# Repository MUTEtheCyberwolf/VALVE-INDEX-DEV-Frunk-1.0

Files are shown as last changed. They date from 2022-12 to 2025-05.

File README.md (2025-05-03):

index_hmd_assembly v29cropped
# VALVE-INDEX-DEV-Frunk-1.0

Mounting System for Developers and Endusers to modify their **Valve Index HMD**.

This Solution is designed to be more **"Beginner"** friendly as well as more open for Modifications. You have a idea for an VR Accessory? Feel free to use the
M4 Mounting points to fix it to your Headset.

## THIS Modification will NOT Void your Headsets Warranty if done properly

# !!! UNPLUG YOUR HEADSET BEFORE WORKING ON IT !!!

# DF1.0 will be marked as complete with the Upload of the Babble Facial Bridge adapter. I am working on a new System the [DF2.0](https://github.com/MUTEtheCyberwolf/Valve-Index-Dev-Frunk-2.0) which will most likely replace the DF1.0 in the long term. Thanks to everyone who supported this first Era of a Open Source Hardware Modding Platform of the INDEX <3

## Repository includes:
 - Base Mounting Frunk
 - HTC VIVE Facial Tracker Mount
 - Project Babble Facetracker Mount (Infograph needs to be updated. You dont need the VIDEV parts but only the FacialTrackerBridgeBABBLEFrunk1.stl/3mf)
 - EyetrackVR Mount (XIAO Boards)
 - EyetrackVR Mount (ESPCAM Boards)
 - VROptician IR Ringlight Mounts (Only works with V2 Lenses) SOON to be Released
 - VROptician EyetrackVR V4 LED Mounts

### These Instructions will show you how to assemble the Mount Parts. You will need additional Parts for the EyetrackVR Tracking. Please take a look at [EyetrackVR Docs](https://docs.eyetrackvr.dev/how_to_build/parts_list) Page.

## Things you need for this Modification:
 - 3D Printer or a 3D Print Service ([PCBWay](https://www.pcbway.com/rapid-prototyping/manufacture/?type=2&reffercode=TOP) or [JLCPCB](https://www.jlc3dp.com/3d-printing-quote) for example)
 - Soldering Iron (I can highly recommend either a [TS101](https://www.welectron.com/Miniware-Soldering-Iron-TS101-I) or a [PINECIL](https://pine64.com/product/pinecil-smart-mini-portable-soldering-iron/). Any cheap 110/230V one also does the Trick)
 - Threaded Heat Inserts. I recommend them either from [Ruthex](https://www.ruthex.de/collections/gewindeeinsatze/products/ruthex-gewindeeinsatz-m4-50-stuck-rx-m4x8-1-messing-gewindebuchsen) or [CNC Kitchen](https://cnckitchen.store/de/products/gewindeeinsatz-threaded-insert-m4-standard-50-stk-pcs)
 - A T5 Torx Screwdriver [iFixit T5 Screwdriver](https://store.ifixit.de/products/t5-torx-screwdriver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) or [iFixit Pro Tech Toolkit](https://store.ifixit.de/products/pro-tech-toolkit) (HIGHLY Recommended)
 - USB-A to USB-C Adaptercable [Choose S1-T5A 10cm](https://de.aliexpress.com/item/1005001319263765.html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) (For now until i release my Fan driver and USB Passthrough Board)
 - RF Shielding Tape [TITAN RF](https://www.amazon.de/TitanRF-Faraday-Tape-High-Shielding-Conductive/dp/B07CRLCGCH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,aps,109) (For the USB Cable)
 - M4 Screws [Amazon Link](https://www.amazon.de/Innensechskantschraube-Edelstahl-Sechskantschraube-Mechanische-Kombinationsbox/dp/B07PRWDHQL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,aps,105) (You will need 6x M4x10/15 and 1x M4x30 for Full Coverage)



index_hmd_assembly v28

# ETVR In Action with DEV Frunk 1.0 and GEN 3 IR Ringlight (Work in Progress)

I am currently tracking only the Right Eye to find the perfect Placement. 

Link to the OSHW Directory of my V1 ETVR Tracking PCB. (ONLY RECOMMENDED FOR PEOPLE WHO KNOW WHAT THEY ARE DOING)
[OSHWLAB Link](https://oshwlab.com/mutethecyberwolf/universal-tracking-module-v1-stt-hub-xiao)

Link to EyeTrackVR: https://github.com/EyeTrackVR

https://github.com/MUTEtheCyberwolf/VALVE-INDEX-DEV-Frunk-1.0/assets/98415183/26b2f5b6-8aac-414c-be2f-e947e9494397

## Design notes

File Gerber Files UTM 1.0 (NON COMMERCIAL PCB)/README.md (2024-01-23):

# THIS VERSION IS ONLY A PROOF OF CONCEPT !

The used IR LED Driver has some Designflaws and can result in high Eyestrain or in worst cases to permanent Eye Damage.
Only try this Build if you know what your doing (or at least more than i do lol) 

## I WILL NOT BE MADE ACCOUNTABLE FOR DAMAGES THAT RESULT FROM INPROPER USE OF THESE RESOURCES!!!

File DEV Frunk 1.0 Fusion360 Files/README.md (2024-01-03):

# VALVE-INDEX-DEV-Frunk-1.0

Here are the Fusion360 Files for User Customization. Feel free to alter them to your Desires but please when Posting Pictures of them refer them to this GitHub Repository.
I will try to keep everything kinda Updated and also continue on improving the HW Designs in the Future. Due to work and other Duties this can sometimes take a while tho so please be patient.

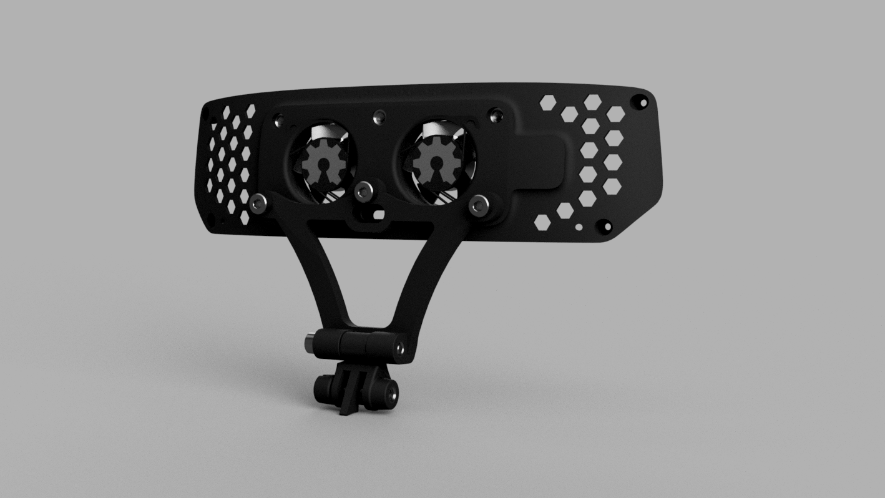
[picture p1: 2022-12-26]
Pictures/VIDEVFrunk1.png

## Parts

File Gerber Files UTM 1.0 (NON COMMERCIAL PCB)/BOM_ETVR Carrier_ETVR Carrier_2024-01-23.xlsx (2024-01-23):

No. | Quantity | Comment | Designator | Footprint | Value | Manufacturer Part | Manufacturer | Supplier Part | Supplier
1 | 4 | 100nF | C1,C2,C4,C6 | C0603 |  | 0603B104M250NT | FH(风华) | C336628 | LCSC
2 | 2 | 10uF | C3,C5 | C0603 |  | 0603F106M6R3NT | FH(风华) | C138601 | LCSC
3 | 4 | 4.7uF | C7,C8,C9,C13 | CAP-SMD_L3.5-W2.8-R-RD |  | TAJB475K035RNJ | Kyocera AVX | C7206 | LCSC
4 | 2 | 100uF | C11,C12 | CASE-B_3528 |  | TAJB107K006RNJ | Kyocera AVX | C16133 | LCSC
5 | 2 | ZHCS400QTA | D1,D2 | SOD-323_L1.8-W1.3-LS2.5-RD |  | ZHCS400QTA | DIODES(美台) | C460116 | LCSC
6 | 2 | BZX384-B3V6,115 | D3,D4 | SOD-323_L1.7-W1.3-LS2.5-RD |  | BZX384-B3V6,115 | Nexperia(安世) | C78071 | LCSC
7 | 2 | NO | DAC/D0/A1,DAC/D0/A2 | SEEEDUINO XIAO ESP32S3 |  | Xiao | Seeeduino |  | Amazon
8 | 1 | FSMD100-1206R | F2 | F1206 |  | FSMD100-1206R | FUZETEC(富致) | C220149 | LCSC
9 | 3 | USB-TYPE-C-017 | FACETRACKER,HOST,SPARE | USB-TYPE-C-SMD_C9900008089 |  | USB-TYPE-C-017 | DEALON(德艺隆) | C2927037 | LCSC
10 | 2 | HC-1.25-4PWT | IRLINKLEFT,IRLINKRIGHT | CONN-SMD_4P-P1.25-HC-1.25-4PWT |  | HC-1.25-4PWT | HCTL(华灿天禄) | C2845381 | LCSC
11 | 2 | 4.7uH | L1,L2 | IND-SMD_L2.0-W1.6 |  | CKCS201610-4.7uH/M | CENKER(岑科) | C354534 | LCSC
12 | 2 | NCD3227YC1 | LED1,LED2 | LED-SMD_4P-L3.2-W2.7-TL |  | NCD3227YC1 | 国星光电 | C2917183 | LCSC
13 | 1 | 2.7kΩ | R1 | R0603 |  | AC0603DR-072K7L | YAGEO(国巨) | C227482 | LCSC
14 | 3 | 100kΩ | R2,R3,R4 | R0603 |  | RTT031003FTP | RALEC(旺诠) | C103200 | LCSC
15 | 1 | 47kΩ | R5 | R0603 |  | FRC0603J473 TS | FOJAN(富捷) | C2907173 | LCSC
16 | 4 | 56kΩ | R6,R9,R10,R11 | R0402 |  | AECR0402F56K0K9 | RESI(开步睿思） | C352409 | LCSC
17 | 2 | 5.1kΩ | R7,R8 | R0402 |  | 0402WGJ0512TCE | UNI-ROYAL(厚声) | C25941 | LCSC
18 | 4 | 100Ω | R12,R13,R16,R17 | R0603 |  | AC0603DR-07100RL | YAGEO(国巨) | C227435 | LCSC
19 | 2 | 330Ω | R14,R15 | R0603 |  | PTFR0603B330RP9 | RESI(开步睿思） | C351654 | LCSC
20 | 2 | 1kΩ | R18,R19 | R0603 |  | SCR0603J1K | VO(翔胜) | C3017736 | LCSC
21 | 2 | - | U1,U7 | QFN-8_L3.0-W3.0-P0.65-TL-EP |  | TPS61042DRBR | TI(德州仪器) | C91304 | LCSC
22 | 2 | S3B-PH-K-S-(LF)(SN) | U2,U6 | CONN-TH_3P-P2.00_S3B-PH-K-S-LF-SN |  | S3B-PH-K-S(LF)(SN) | JST | C157929 | LCSC
23 | 1 | FE1.1S | U4 | SSOP-28_L9.9-W3.9-P0.64-LS6.0-BL-1 |  | FE1.1S-BSOP28BCN | TERMINUS | C9359 | LCSC
24 | 1 | - | X1 | OSC-SMD_4P-L3.2-W2.5-BL |  | XXFCELNANF-12M | TAITIEN(泰艺电子) | C124308 | LCSC

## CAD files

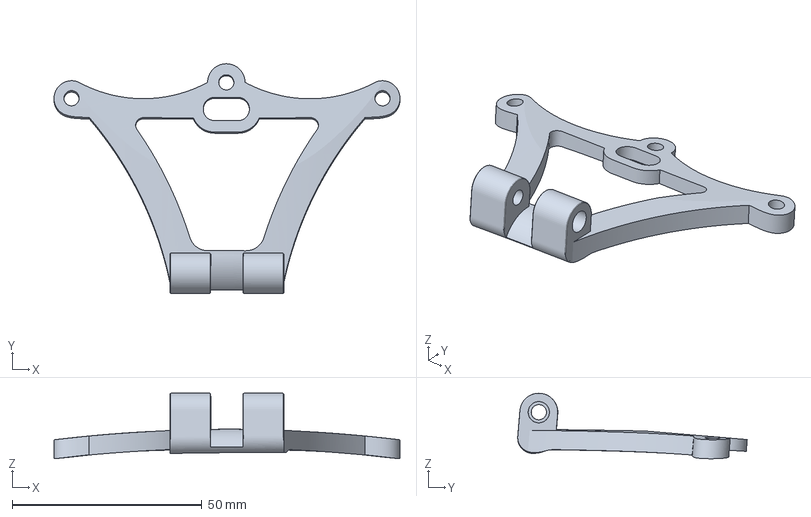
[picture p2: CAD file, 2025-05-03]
3D Print Files 3mf/FacialTrackerBridgeBABBLEFrunk1.3mf
91.1 x 60.5 x 17.3 mm

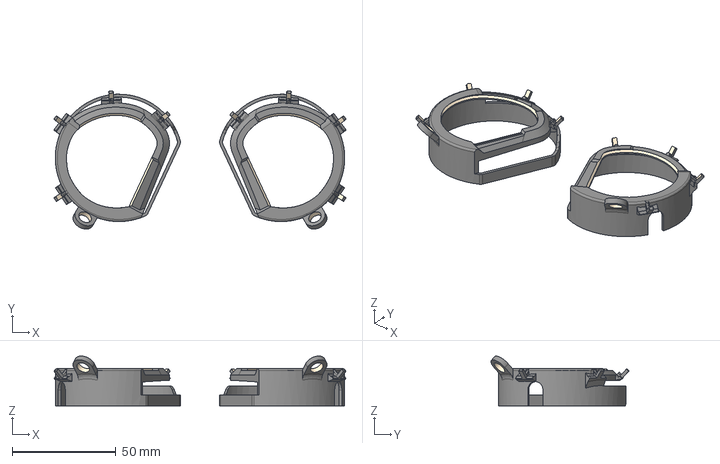
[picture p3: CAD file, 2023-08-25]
3D Print Files STL(Ascii)/Gen 3 Prohurtz V2 Mounts (VROptician)/MUTE VROptician Gen 3 Mounts for Prohurtz V2 IR LED's.step
140.9 x 66.7 x 24.1 mm

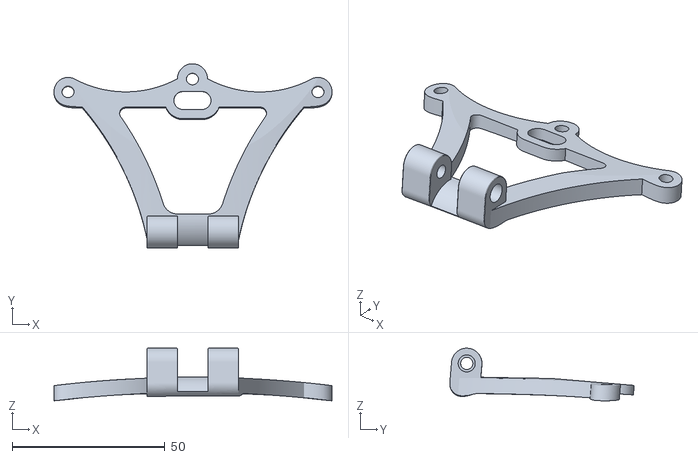
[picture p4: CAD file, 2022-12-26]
Basic Setup for Vive Facial Tracker/FacialTrackerBridgeVIDEVFrunk1.stl
91.1 x 60.5 x 17.3

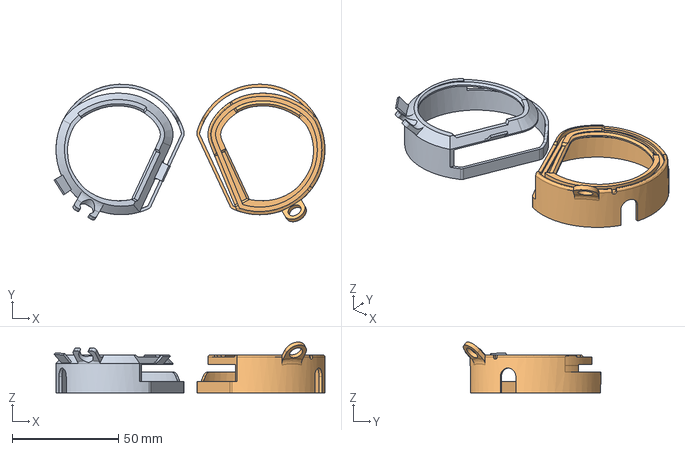
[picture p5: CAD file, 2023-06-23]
INDEX VROptician Gen 3 Lense Mounts (Prototype not final)/Index Lense Carrier Gen 3.step
127.6 x 64.8 x 24.0 mm

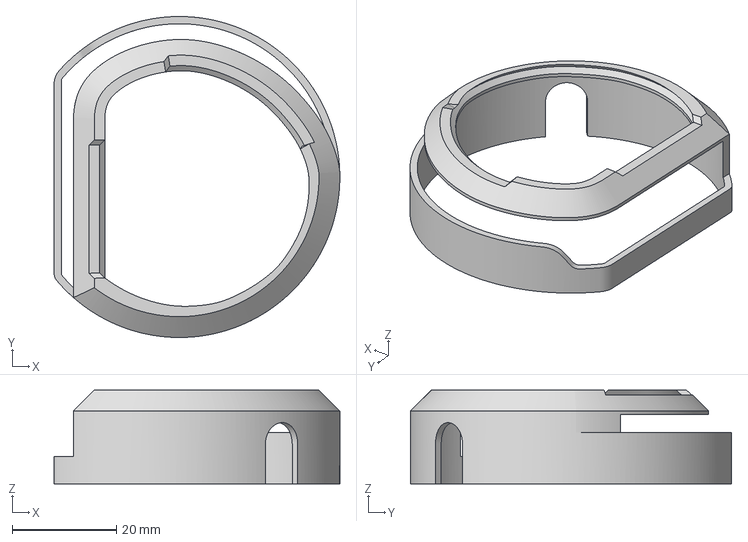
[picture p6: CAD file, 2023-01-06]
INDEX VROptician LENSE Base + Edits/ETVR INDEX VROptician LENSE Mount.3mf
54.7 x 61.5 x 18.0 mm

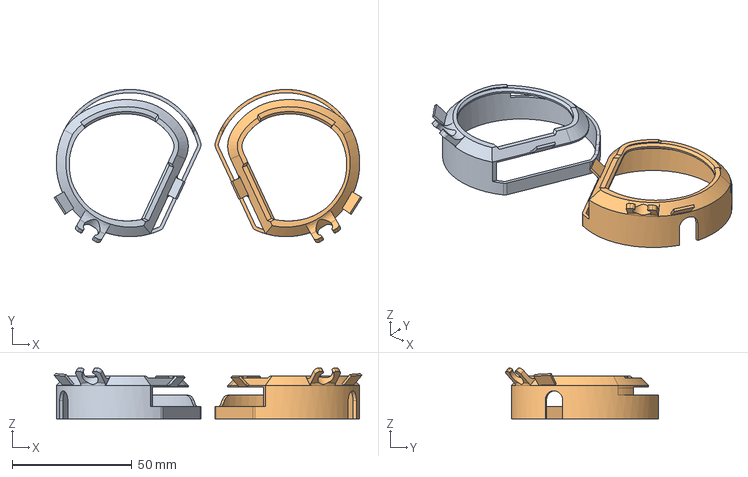
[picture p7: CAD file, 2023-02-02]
INDEX VROptician LENSE Base + Edits/V1.0A Edit with Twin LED and Camera Mount/INDEX VROptician Lense Mounts (2022).step
128.6 x 63.9 x 21.2 mm

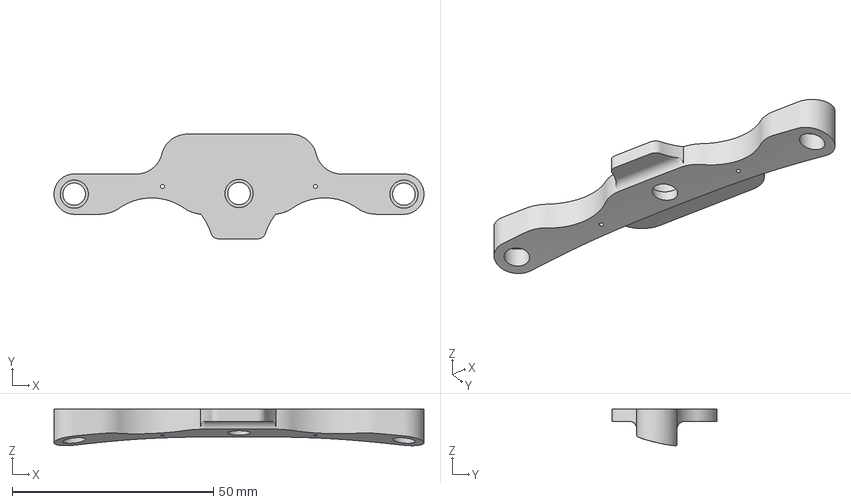
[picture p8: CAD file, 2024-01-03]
3D Print Files 3mf/UTM V1.0 Mount.3mf
91.9 x 26.0 x 9.08 mm

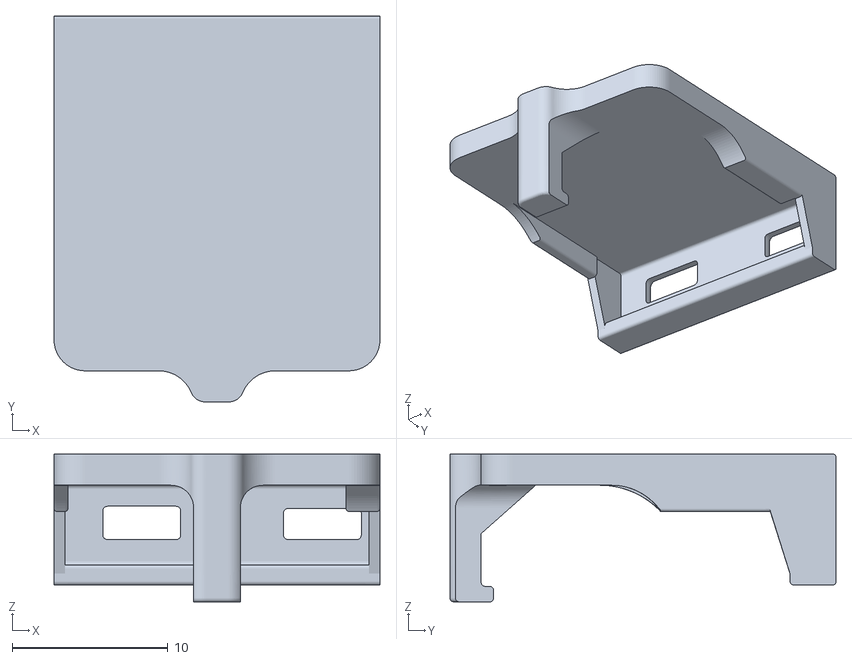
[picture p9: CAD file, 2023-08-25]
3D Print Files STL(Ascii)/Coverplate XIAO Retention Clip V4 PCB No Logo.stl
20.9 x 24.8 x 9.49

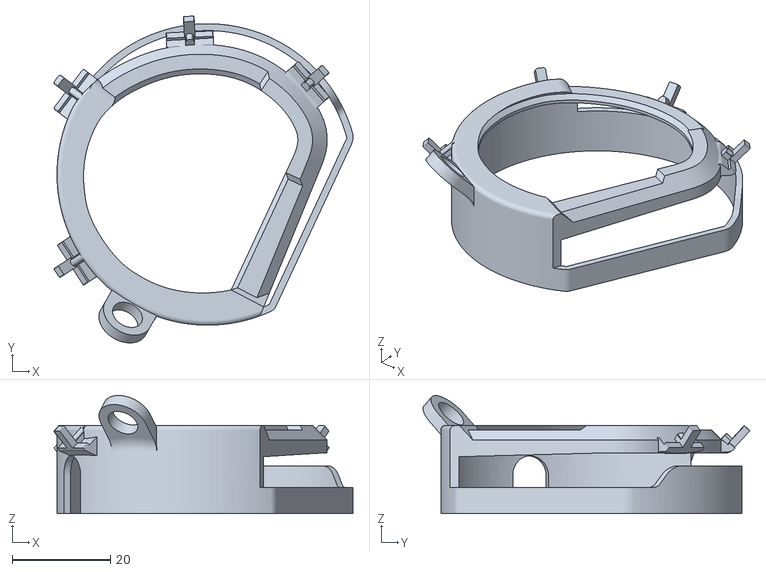
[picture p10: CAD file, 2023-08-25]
3D Print Files STL(Ascii)/Gen 3 Prohurtz V2 Mounts (VROptician)/Gen_3_Prohurtz_V2_Mount Verified (Tight Fit) L.stl
61.0 x 66.7 x 24.1

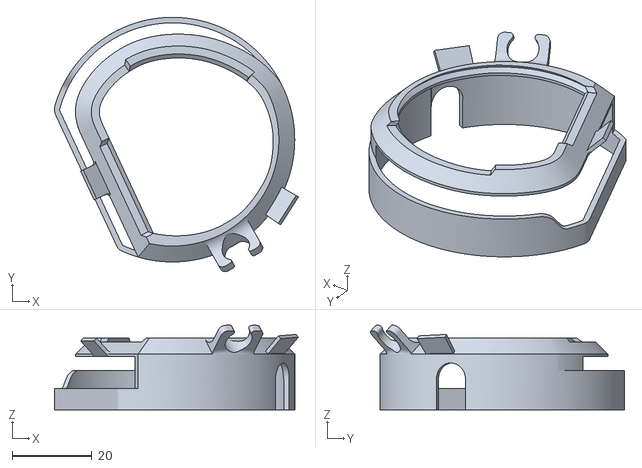
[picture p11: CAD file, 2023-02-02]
INDEX VROptician LENSE Base + Edits/V1.0A Edit with Twin LED and Camera Mount/INDEX VROptician Lense Mounts (2022) Right.stl
61.3 x 63.9 x 21.2

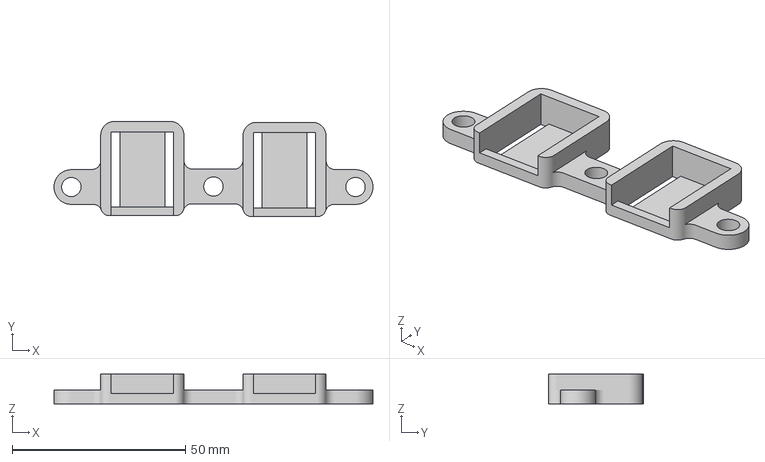
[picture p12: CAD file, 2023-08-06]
3D Print Files 3mf/Eyetrack VR Prototype XIAO.3mf
92.0 x 27.5 x 8.60 mm

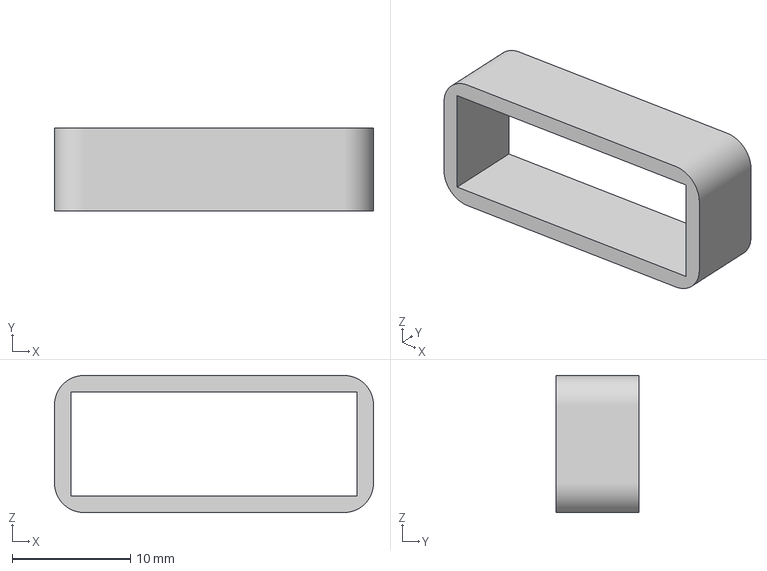
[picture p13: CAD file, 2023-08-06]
3D Print Files 3mf/XIAO Retention Clip.3mf
27.0 x 7.00 x 11.6 mm

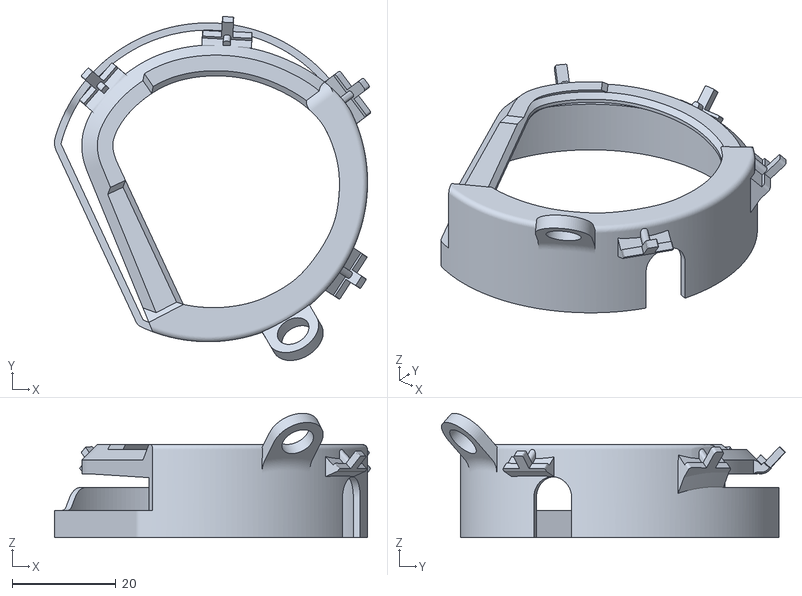
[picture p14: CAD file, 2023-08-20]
3D Print Files STL(Ascii)/Gen_3_Prohurtz_V2_Mount Unverified.stl
61.0 x 66.4 x 24.0

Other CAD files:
3D Print Files STL(Ascii)/FacialTrackerBridgeBABBLEFrunk1.stl
INDEX VROptician LENSE Base + Edits/ETVR INDEX VROptician LENSE Mounts.step
3D Print Files STL(Ascii)/Coverplate for XIAO Retention Clip V4 PCB.stl
3D Print Files STL(Ascii)/Gen 3 Prohurtz V2 Mounts (VROptician)/Gen_3_Prohurtz_V2_Mount Verified (Tight Fit) R.stl
INDEX VROptician LENSE Base + Edits/V1.0A Edit with Twin LED and Camera Mount/INDEX VROptician Lense Mounts (2022) Left.stl
3D Print Files 3mf/EyetrackVRDemoVIDEVFrunk1.3mf
3D Print Files 3mf/FacialTrackerBeerHingeVIDEVFrunk1.3mf
3D Print Files 3mf/FacialTrackerBridgeVIDEVFrunk1.3mf
3D Print Files 3mf/ValveIndexDEVFrunk1.3mf
3D Print Files STL(Ascii)/Eyetrack VR Prototype XIAO Mount.stl
3D Print Files STL(Ascii)/EyetrackVRDemoVIDEVFrunk1.stl
3D Print Files STL(Ascii)/XIAO Retention Clip for V4 PCB No Letters.stl
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

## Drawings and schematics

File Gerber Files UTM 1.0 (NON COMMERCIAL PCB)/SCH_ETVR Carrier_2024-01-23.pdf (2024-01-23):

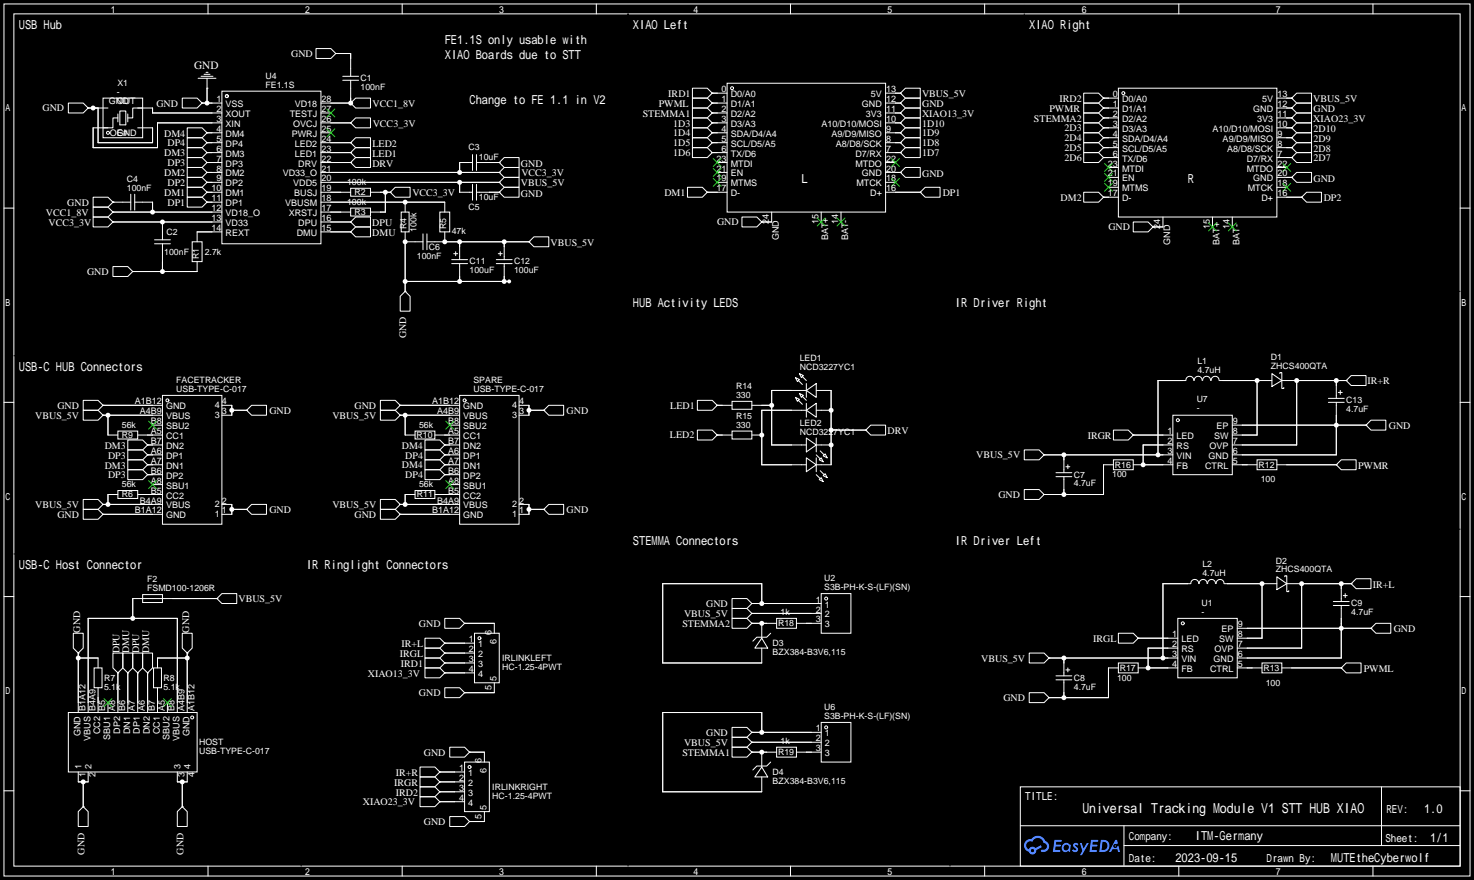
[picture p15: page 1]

FE1.1S only usable with
XIAO Boards due to STT

Change to FE 1.1 in V2

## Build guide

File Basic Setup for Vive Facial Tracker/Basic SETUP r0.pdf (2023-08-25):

MUTE | VALVE INDEX DEV FRUNK 1.0 HW INSTALLATION GUIDE | Rev. 0

Thank you for downloading the VALVE INDEX DEV FRUNK 1.0 3D Printing Files.

This Document should help you with:

- Getting the necessary Parts printed
- Insert the threaded Inserts into your Part
- Removing the Factory Frunk from your INDEX HMD
- Installing the DEV Frunk in your HMD
- Connecting the Facial Tracker to your HMD

Before we Start one little Reminder.

So what Parts do we need except the 3D Printed Parts?

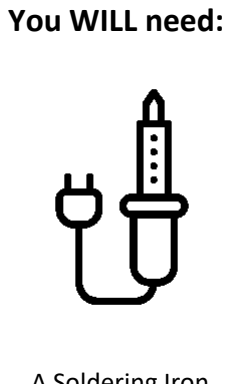
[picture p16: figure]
You WILL need:

Getting the Parts printed:

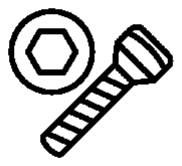
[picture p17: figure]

I moved the needed 3D Printed Parts into a dedicated Folder in the GitHub Repository named:

\VALVE-INDEX-DEV-Frunk-1.0\Basic Setup for Vive Facial Tracker

It consists of the 3 Files that you either send to a 3D Print Supplier like JLCPCB or you ask a Friend with a Printer to make them for you. Support Structures are needed on regular FDM Printers and I recommend the use of SLS printed NYLON. Otherwise you will also be good with using PETG for the Printed Parts ^^

All INDEX HW Mods that I make are NON-Destructive. YOUR Warranty should NOT be Voided by INSTALLING the DEV Frunk. Depending on where you live a denial of your Warranty can be a Crime so don’t worry. If you don’t actively try to break your 500$ HMD you will be fine.

I therefore still will not be held accountable for any Damage you do on YOUR Hardware.

A Soldering Iron
with a Tip Similar
to a HAKKO T18-B
(or comparable
you will need it for
the Inserts)

Threaded M4
Inserts (DEV Frunk
is designed for
RUTHEX M4
Inserts others
should work too)

6x M4x10 Metric
Screws (You can
choose but I
recommend Allen
Screws)

1x M4x30 (For the
Beerhinge)

A Torx T5 Bit and
Holder or a T5
Screwdriver

I HIGHLY
recommend to
buy a IFIXIT Pro
Tech Toolkit for
the Future of this
Project.

A USB-A to USB
type C Female
Adapter.
Preferably one of
the small
combined ones.

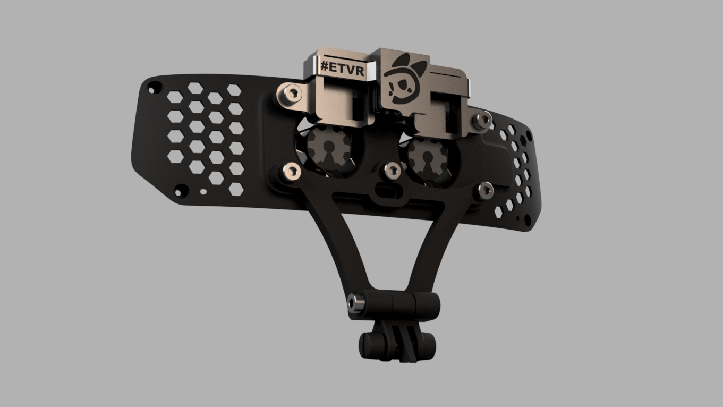
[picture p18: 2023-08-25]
Pictures/index_hmd_assembly v28 .png

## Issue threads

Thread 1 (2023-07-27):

[Doc] Fans

tomaae, 2023-07-27:
Hi,
I'm quite interested in this project.
Could you please document which fans/fan assembly are you using with this project?

MUTEtheCyberwolf, 2023-08-11:
The Fan Assembly is currently in development. A direct connection to the Eyetracking ESP's is possible. The Frunk was designed for two 30x30x7mm Fans that Pressfit into the Carrier Plate from the Inside.

Those here will do the Trick.

https://de.aliexpress.com/item/1005004661799681.html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

tomaae, 2023-08-12:
perfect, thanks. I still have time to cancel my noctua 40x40x10 fan order then. should have measured it, silly me.
being in development is fine, it will take a while to get all components I need anyway and in worst case can always just jury rig my own temporary controller and air duct.
I was also looking into xiao mount, wont it significantly cover fan exhaust? I may look into redesigning it once I get all components, I'm still waiting for IR V4 board. I will need to see how cables can be managed there first.

Btw, where did you get this right angle usb socket? that looks very clean.
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

MUTEtheCyberwolf, 2023-08-12:
The XIAO Mount was designed with reduced Sensor Occlusion in mind. The Final Eyetracking PCB will take care of that by moving them closer together.  A User on Discord already printed the XIAO design. It occludes the Airflow a little bit but that will be taken care of with the final Version. The Fans have enough Pressure to get the hot Air out tho.  Props to @Captaincat for the clean build.
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
The 90° Connector can be purchased from Amazon without any problems.
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

tomaae, 2023-08-12:
oh yea, that looks really good. so one in github screenshot is something different, just looking similar. I will probably look into having those xiao board fully covered for both eastethic and component safety. that should be easy tho.
Maybe adding some dust filter behind those holes, so dust wont settle in when headset is left on the stand.
Thanks for all the sources, I'm going to order everything. And of course, thanks for excellent job on this project.

MUTEtheCyberwolf, 2023-08-13:
That Hub should be fine. The Picture linked to the Github was a early version of the Frunk using the Old ESPCAM Modules which are currently obsolete. I prefer and highly recommend using the XIAOs with USB Serial instead of WIFI. You can add Dustfilters but make sure they are not too dense. The Hole size is actually increased to allow a better Airflow through the Frunk. That would result in lower fanspeeds/quieter Operations and also better Thermal Management.

I would also recommend you to join the EyetrackVR Discord.

The Fans will be Documented when the Controller is officially out. Until then I would Close this Issue.

Closed 2023-08-13.

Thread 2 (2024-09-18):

Questions about the PCB

Thelvaen, 2024-09-18:
Hello,

First of all, many thanks for your project, it really goes in the right direction for that kind of accessories (Valve should have made the frunk with the screw inserts from the start I think).

I wanted to take a look at the PCB, sadly it's missing the pick'n'place file (CPL) that would be required to order it with component placed through JLCPCB.

You probably could just publish your EasyEDA project to oshwlab, so everything required to just "order" the PCB with "almost" everything on it from JLCPCB would be there.

Regards,
Thelvaen

MUTEtheCyberwolf, 2024-09-24:
Can try to do that the upcoming days. I don't really recommend using the old PCB Design anymore since i had some issues with the HUB Controller on it. It "might" work flawlessley with the Project Babble Facial tracker but i haven't tested it yet.

Thelvaen, 2024-09-24:
Having it on OSHWlab would allow people to fork it and try to improve it / or simplify it depending on their needs :)

MUTEtheCyberwolf, 2024-09-26:
OSHWLAB Link has been added. The PCB Project is unlisted tho everyone can get the design files from there through the link in the Readme.

Closed 2024-09-26.

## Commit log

2022-12-26 Base File Upload
    Base Print Files.
    -Removed glue Bridge from Facetracker Bridge.
    [FacialTrackerBeerHingeVIDEVFrunk1.3mf, FacialTrackerBridgeVIDEVFrunk1.3mf, ValveIndexDEVFrunk1.3mf]
2022-12-26 Create EyetrackVRDemoVIDEVFrunk1.3mf
    Added first Prototype Mount for Valve Index DEV Frunk 1
    [EyetrackVRDemoVIDEVFrunk1.3mf]
2022-12-26 Added STL(Ascii) Files
    -Added STL Files
    -Removed old Index Frunk Prototype
    [EyetrackVRDemoVIDEVFrunk1.stl, FacialTrackerBridgeVIDEVFrunk1.stl]
2023-01-06 Lense Base
    Added Index Lense Base for Making ETVR Mounts with VROptician Lenses.
    - Need to add Clips for the Camera and IR LEDs.
    - Working on LED PCB which allows adjustment of position with Soldering Iron.
    [ETVR INDEX VROptician LENSE Mount.3mf, ETVR INDEX VROptician LENSE Mounts.f3d, ETVR INDEX VROptician LENSE Mounts.step]
2023-02-02 Added Adapter Lensemounts
    Lensemounts with TwinLED and Camera have been added
    [INDEX VROptician Lense Mounts (2022) Left.stl, INDEX VROptician Lense Mounts (2022) Right.stl, INDEX VROptician Lense Mounts (2022).f3d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]
2023-02-16 Added Lense Mounts for Old VROptician Lenses
    [ETVR VROptician Lense Adapters Pre2020 v2.f3d, ETVR VROptician Lense Adapters Pre2020 v2.step, ETVR VROptician Lense Adapters Pre2020 v2.stl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]
2023-06-23 Gen 3
    Added Gen 3 Prototype Mounts (Prototype not final) to Repository
    IREmitters PCBs Gen 3 soon to come.
    [INDEX Lense Carrier Gen 3.f3d, Index Lense Carrier Gen 3.step]
2023-07-26 Added Basic Setup Folder
    Basic Setup Instructions added.
    ATTENTION!!! Work in Progress not finished !
    Moved 3D Print Files to this Directory that are needed for this Step.
    [FacialTrackerBridgeVIDEVFrunk1.stl]
2023-08-06 New Mount
    Added XIAO Mount with Retainer Clip that slides over it. Needed Pins are Exposed from both sides to be easily soldered onto.
    [Eyetrack VR Prototype XIAO Mount.stl, Eyetrack VR Prototype XIAO.3mf, XIAO Retention Clip.3mf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]
2023-08-11 V4 PCB UPDATE
    After a Request from "captaincat" and "Prohurtz" i added a quick Mount that attaches the soon released V4 LED Driverboard to the XIAO Carrier Plate through the Retainer Mechanism. THIS is a very Earl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
    [Coverplate XIAO Retention Clip V4 PCB No Logo.stl, Coverplate for XIAO Retention Clip V4 PCB.stl, XIAO Retention Clip for V4 PCB No Letters.stl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]
2023-08-20 Create Gen_3_Prohurtz_V2_Mount Unverified.stl
    Add Gen 3 Mount for Prohurtz V2 IR LEDs
    VROptician early 2022>now compatible
    [Gen_3_Prohurtz_V2_Mount Unverified.stl]
2023-08-25 Slight Adaption to the Coverplates
    Now easier to insert Plug into V4 PCB from top.
    [Coverplate XIAO Retention Clip V4 PCB No Logo.stl, Coverplate for XIAO Retention Clip V4 PCB.stl]
2023-08-25 Create Gen_3_Prohurtz_V2_Mount Verified (Tight Fit).stl
    Added Updated V2 IR LED Mount
    [Gen_3_Prohurtz_V2_Mount Verified (Tight Fit).stl]
2023-08-25 Added Mirrored Version of V2
    Added Left Version of V2
    [Gen_3_Prohurtz_V2_Mount Verified (Tight Fit) L.stl, Gen_3_Prohurtz_V2_Mount Verified (Tight Fit) R.stl]
2023-08-25 Organized stuff
    [Gen_3_Prohurtz_V2_Mount Loose Fit (old Unverified).stl, Gen_3_Prohurtz_V2_Mount Verified (Tight Fit) L.stl, Gen_3_Prohurtz_V2_Mount Verified (Tight Fit) R.stl]
2023-08-25 Create MUTE VROptician Gen 3 Mounts for Prohurtz V2 IR LED's.step
    Added STEP Files for User Customization.
    I know i hack stuff together sometimes xD
    [MUTE VROptician Gen 3 Mounts for Prohurtz V2 IR LED's.step]
2023-09-29 Added Fusion360 Base Files
    Added the Fusion 360 Files of the:
    ~Base Frunk Mount
    ~Facial Connector
    ~Facial Hinge (Beerhinge)
    [FacialConnector.f3d, FacialHinge.f3d]
2024-01-03 Create UTM V1.0 Mount.3mf
    V1.0 Mount Limited Run Not recommended for Mass Usage.
    DEVELOPER MOUNT
    [UTM V1.0 Mount.3mf]
2024-01-23 Added Gerber Files for UTM 1.0
    Added the Gerber Files, Schematics and BOM for the UTM 1.0 PCB.
    This Design is no longer recommended and is not advised for commercial use. UTM 2.0 will replace this in the near Future. Please don't mess with this if you don't know much about Electronics. The used LED Driver on this PCB needs some adjustments that could if not done properly increase the Eyestrain and in worst case add permanent Eye damage to you.
    All you do with this is up to your own responsibility. I will NOT be made accountable for damage that results of misuse of those Resources.
    [BOM_ETVR Carrier_ETVR Carrier_2024-01-23.xlsx]
2024-04-16 Update README.md
    Added FlowChart for Printing Parts
2024-09-26 Update README.md
    Updated OSHWLAB Link to V1 PCB
2025-05-03 Added Babble Facial Bridge
    Just a very small update. Adding the Mount for the Babble tracker. Assembly is Similar to the VIVE Facial bridge but you dont have the beerhinge Part (yet)
    [FacialTrackerBridgeBABBLEFrunk1.3mf, FacialTrackerBridgeBABBLEFrunk1.stl]
